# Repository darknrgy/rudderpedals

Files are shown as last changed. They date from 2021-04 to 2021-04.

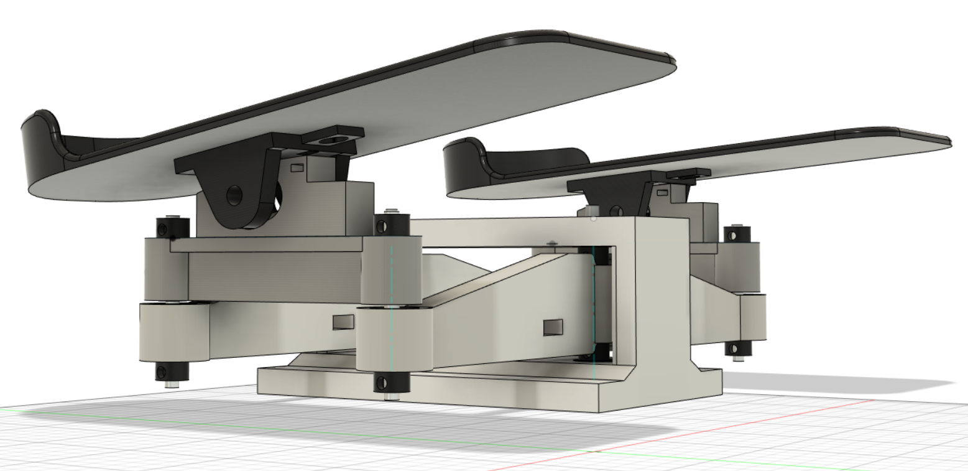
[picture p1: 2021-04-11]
Images/Pedal Assembly.png

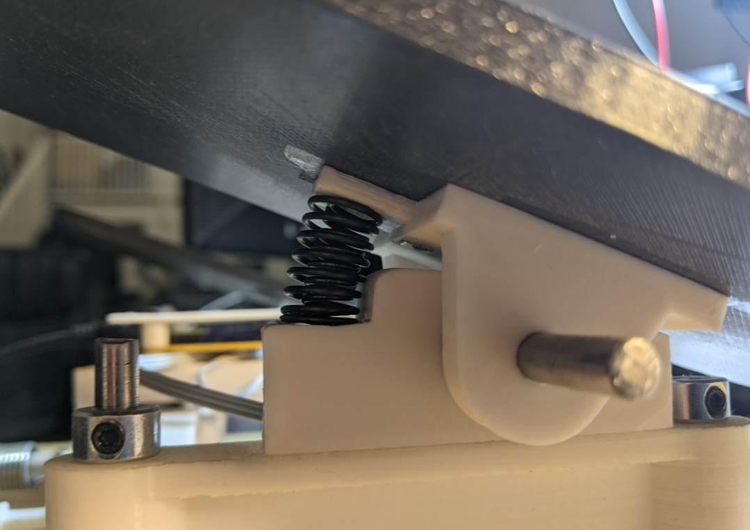
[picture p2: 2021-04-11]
Images/Pedal Spring.png

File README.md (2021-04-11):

# 3D Printed Flight Simulator Rudder Pedals

This is a set of flight simulator rudder pedals that I built from scratch. My copy is currently functional and being used in Microsoft Flight Simulator. This is a fairly crude design and is provided as-is with no support. Expect to iterate and improve the design. 

https://www.thingiverse.com/thing:4824134

https://youtu.be/vinw3yeDGUQ

## Materials
- All parts printed in PLA on an Anycubic Chiron
- Shims - https://www.amazon.com/gp/product/B004K1FF0K/ref=ppx_yo_dt_b_search_asin_title?ie=UTF8&psc=1
- Bearings - https://www.amazon.com/gp/product/B07GT739PV/ref=ppx_yo_dt_b_search_asin_title?ie=UTF8&psc=1
- Shaft - https://www.mcmaster.com/catalog/127/1241
- Collar - https://www.mcmaster.com/catalog/127/1335
- Hall sensor - https://www.digikey.com/en/products/detail/honeywell-sensing-and-productivity-solutions/SS49E/701361
- Main Spring - https://www.thespringstore.com/pe076-718-24014-mw-2750-mh-n-in.html
- Pedal Spring Options - https://www.amazon.com/gp/product/B008RG8LXW/ref=ppx_yo_dt_b_search_asin_title?ie=UTF8&psc=1
- Magnets - Search amazon for "5mm cube magnets" for the lowest price
- Arduino Micro
- Various wires, header pins, usb cable, nuts and bolts

## Construction Notes
- Reference the youtube video for additional notes
- Reference the included images
- The arms are 300mm long and will dictate the minimum size printer (but they can be printed diaganoally)
- The shafts must be cut to size and their diameter must be ground down to fit in the bearings. I put the cut shafts into a drill press and ground them with sand paper. 
- There are 8 shafts total:
  - 61mm rail shaft X4
  - 57mm pedal shaft X2
  - 72mm center shaft X2
- Some pieces are glued together with super thin cyanoacrolate (superglue). For best adhesion, sand the mating surfaces down to a very fine grain - 1000 git or more, and apply a thin and even layer of glue. 
  - Pedal is glued to Pedal Hinge
  - Rail Top is glued to Rail Bottom
  - Hall Sensor Mount is glued to Frame
  - Magnet Mount is glued to one of the Arms
- The hall sensor I chose may not be the best candidate. I get less resolution than I would really want. One of the parameters in the datasheet is "Magnetic Range", which for the SS49E is +/- 1000 Gauss. If I were to do it again, I would choose a smaller magnetic range for higher resolution. 
- The magnets interact with the sensor in a way that requires a specific orientation and distances. Experiment with a simple test setup to familiarize yourself with the behavior. 
- The circuit is very simple. It is powered by the usb port. The hall sensors require 5V, ground, and output a 0-5v signal that is read with analogRead(). 
- Pay special attention to how the springs are mounted in the video - they are latching and will self center. 
- The assembled product was mounted to a board with screws. The Spring Posts are hot glued to the board. 

## Programming Notes
- This project uses Arduino Joystick Library https://github.com/MHeironimus/ArduinoJoystickLibrary
- ArduinoJoystickLibrary requires an arduino or clone that uses the ATmega32u4, although I expect that the library could be ported if you have more programming skill than ATmega32u4 buying skills. 
- There is a physical calibration step that is independent of Windows joystick calibration. I printed values from within the microcontroller over serial and tuned these values for each axis:
  -	top - the highest raw ADC value
  - bottom - the lowest raw ADC value
  - expoV - exponential curve coefficient, 1 is linear, see source for my values. You may find a more formal way of finding this value but I just used trial and error.

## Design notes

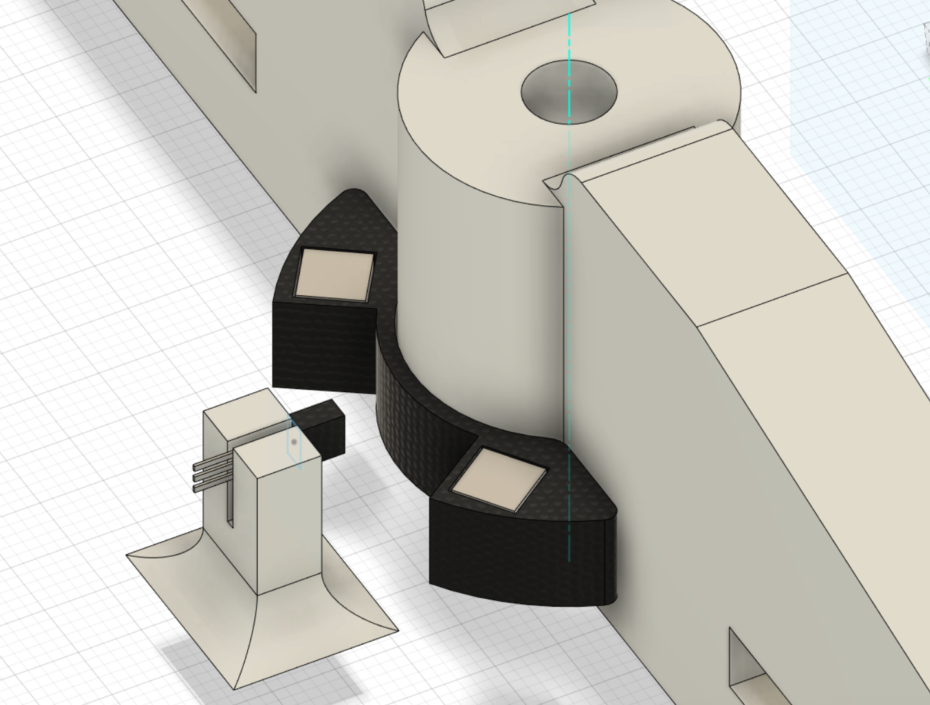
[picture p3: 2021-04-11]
Images/Hall Sensor.png

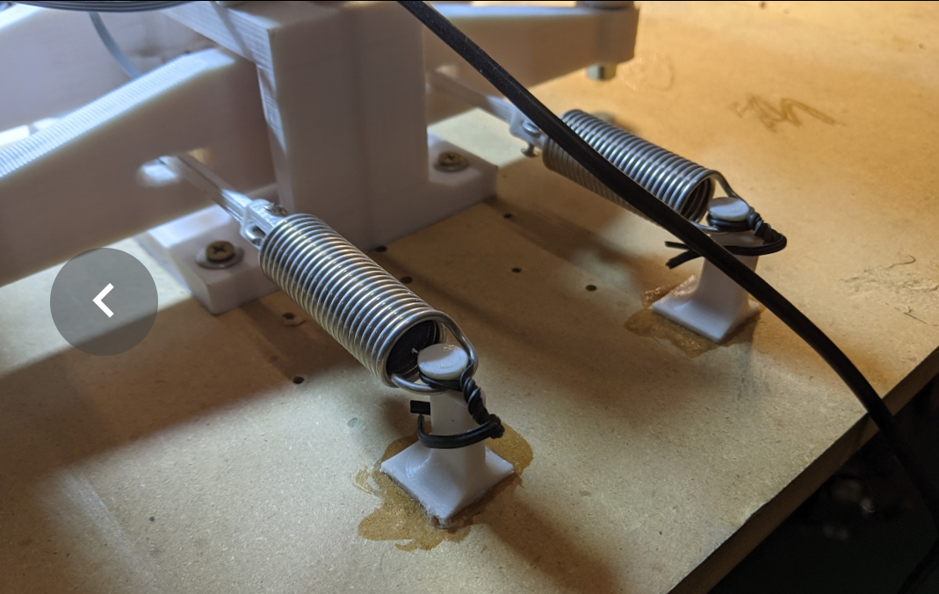
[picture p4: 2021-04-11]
Images/Main Spring.png

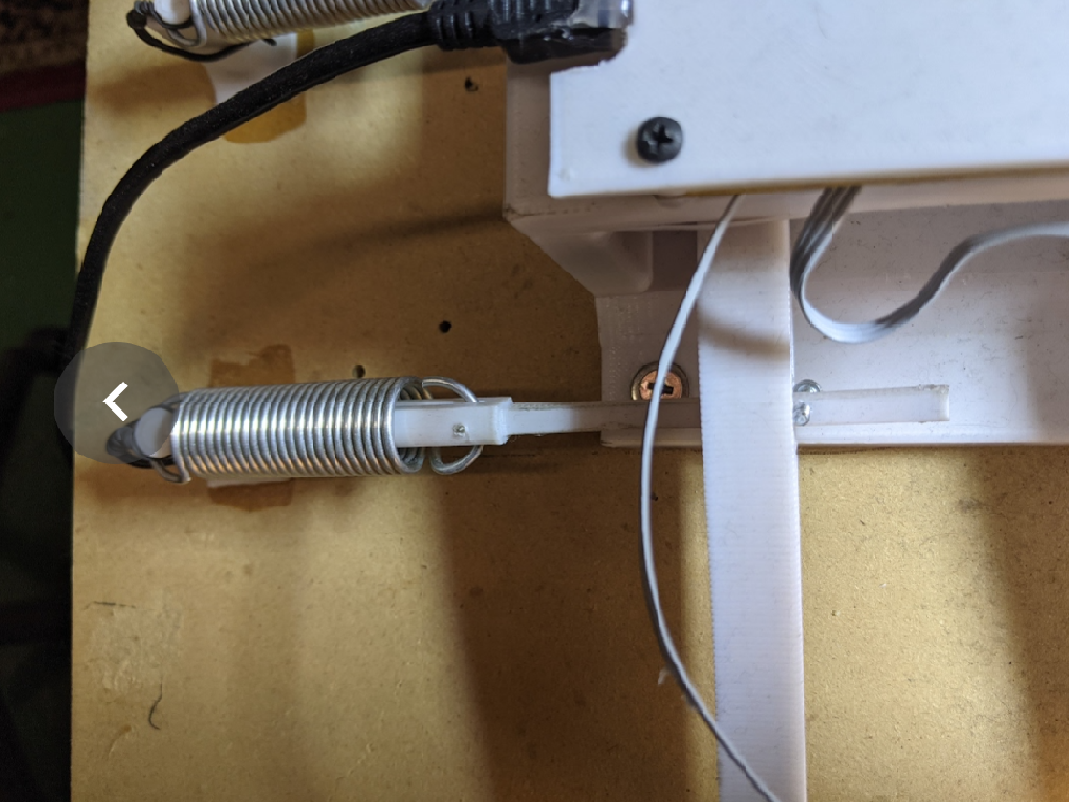
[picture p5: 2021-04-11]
Images/Main Spring (overhead).png

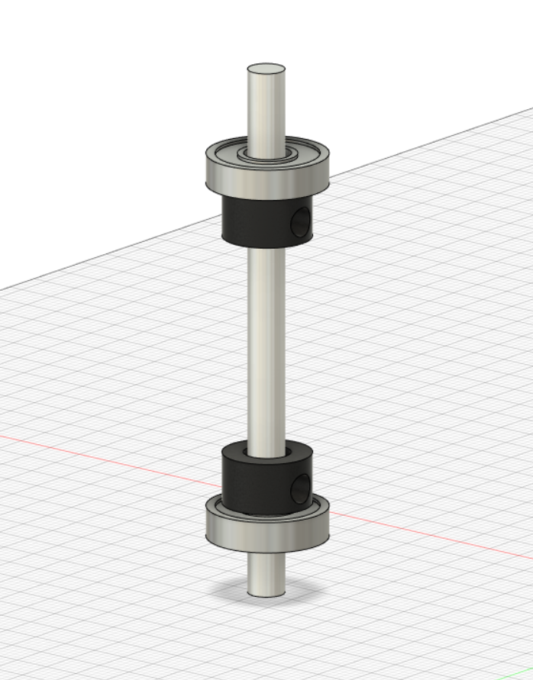
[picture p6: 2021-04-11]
Images/Center Shaft.png

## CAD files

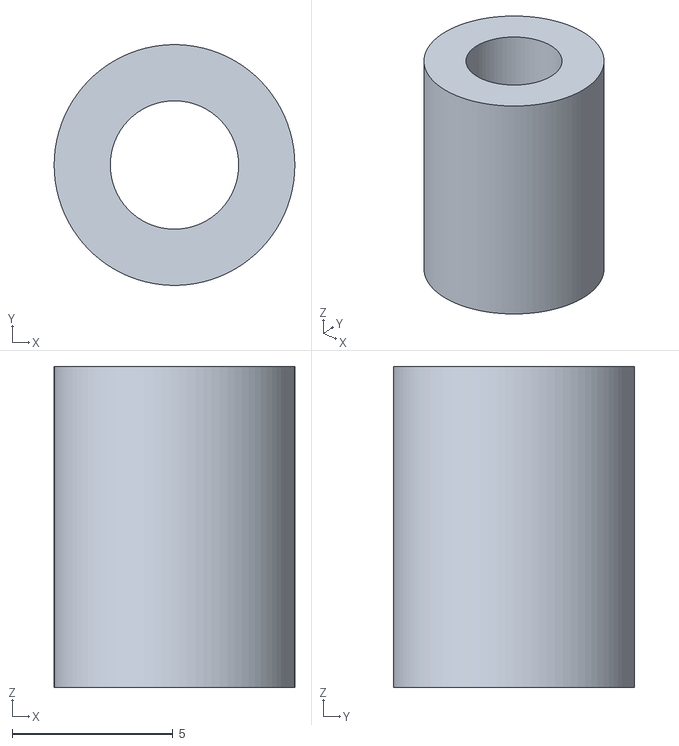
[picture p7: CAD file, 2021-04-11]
STL/Circuit Board Riser.stl
7.50 x 7.50 x 10.0

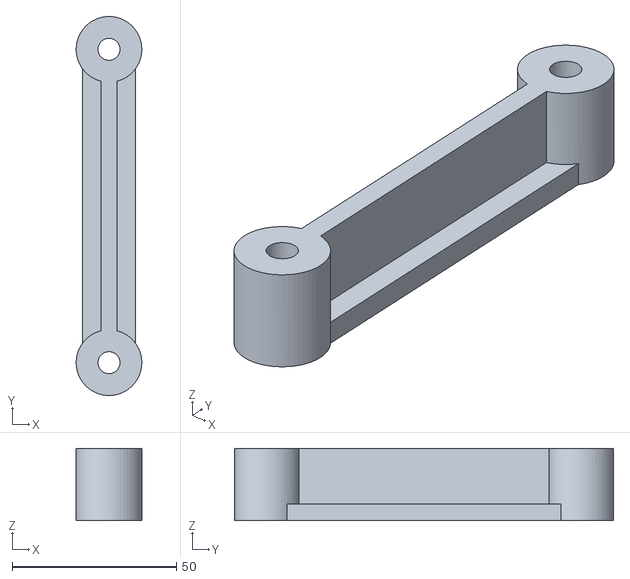
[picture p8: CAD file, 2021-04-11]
STL/Rail Bottom.stl
20.0 x 115.4 x 22.0

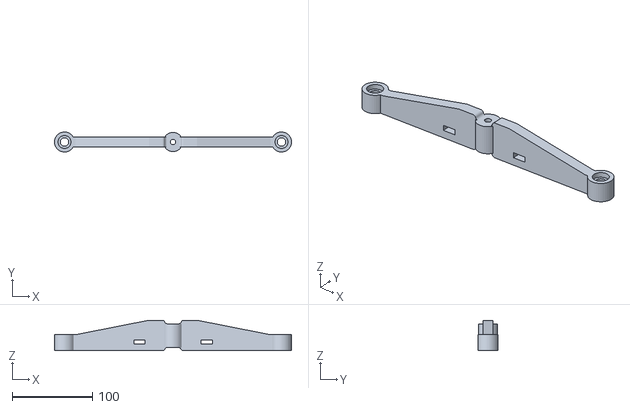
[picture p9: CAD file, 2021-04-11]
STL/Arm.stl
295.5 x 25.0 x 38.0

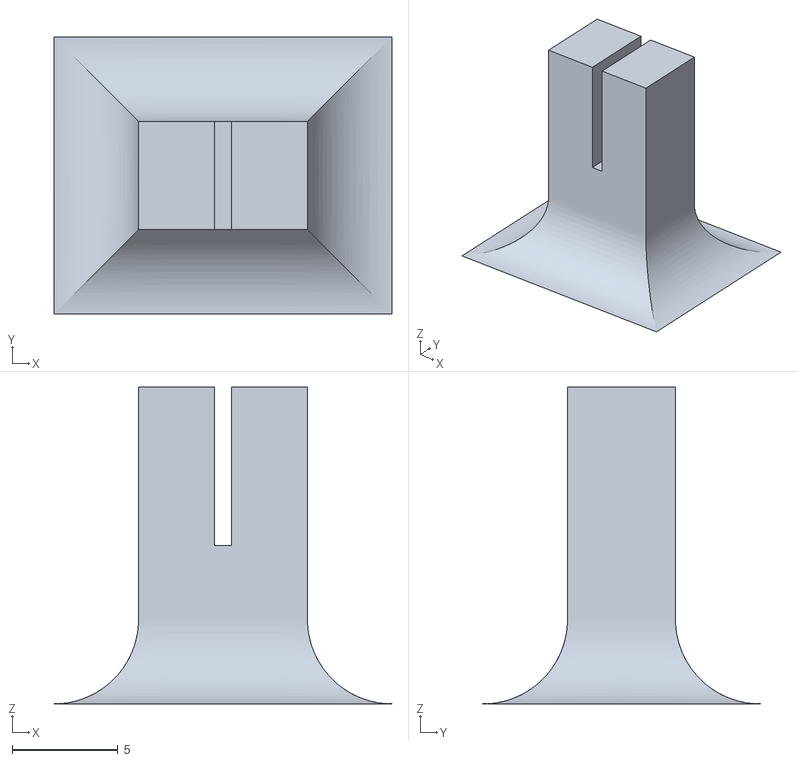
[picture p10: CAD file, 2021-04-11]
STL/Hall Sensor Mount.stl
16.0 x 13.1 x 15.0

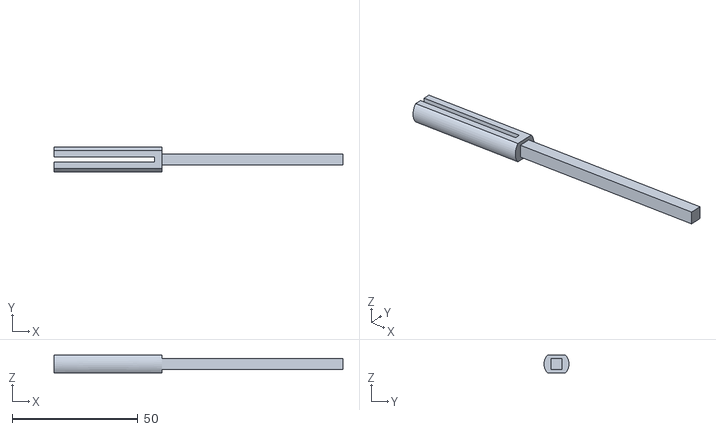
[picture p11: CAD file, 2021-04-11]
STL/Spring Rod.stl
115.0 x 10.0 x 7.00

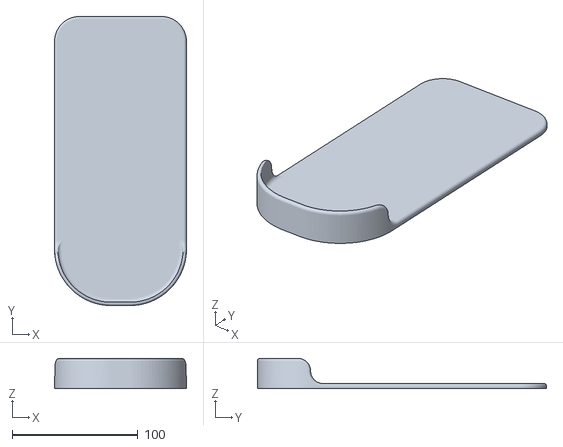
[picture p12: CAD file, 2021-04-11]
STL/Pedal.stl
105.0 x 230.0 x 24.0

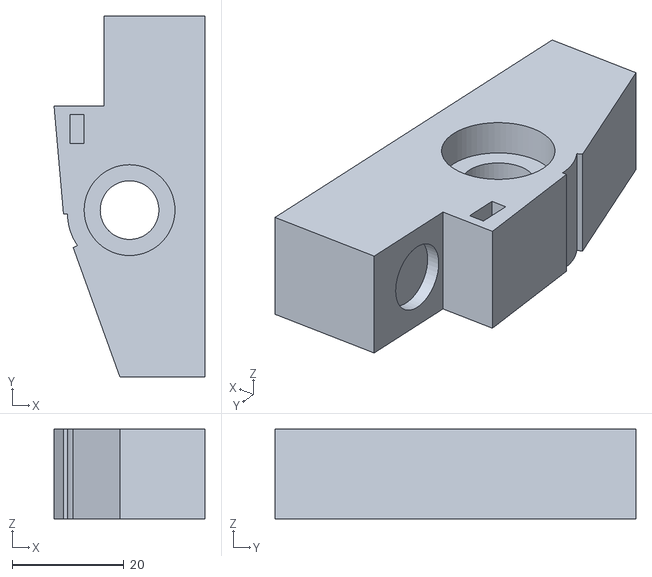
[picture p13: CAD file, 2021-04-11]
STL/Rail Top.stl
27.0 x 64.4 x 16.0

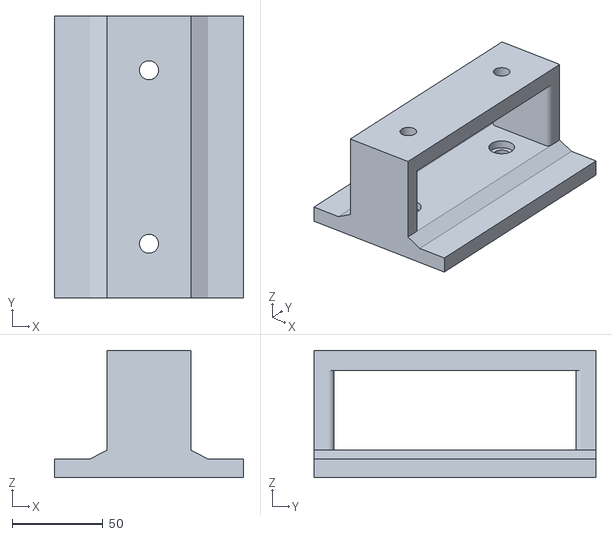
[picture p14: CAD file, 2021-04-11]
STL/Frame.stl
104.0 x 155.0 x 70.0

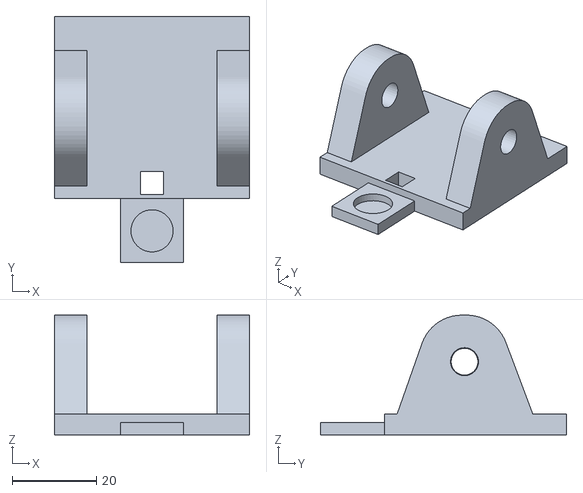
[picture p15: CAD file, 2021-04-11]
STL/Pedal Hinge.stl
46.3 x 58.3 x 28.4

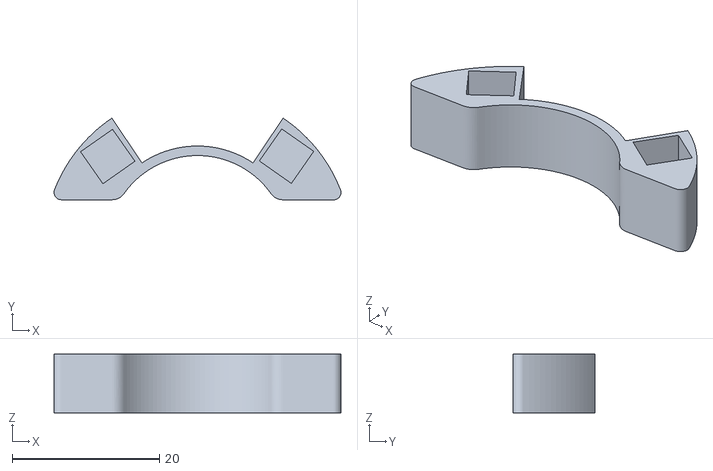
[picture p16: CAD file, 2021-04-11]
STL/Magnet Mount.stl
38.9 x 11.1 x 8.00

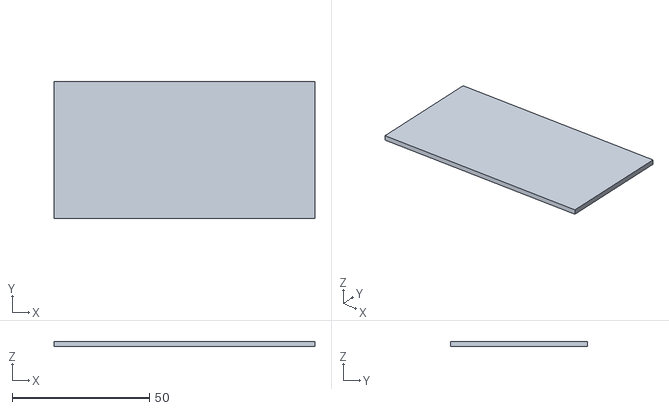
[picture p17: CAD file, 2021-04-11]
STL/Circuit Board Panel.stl
95.0 x 50.0 x 2.00

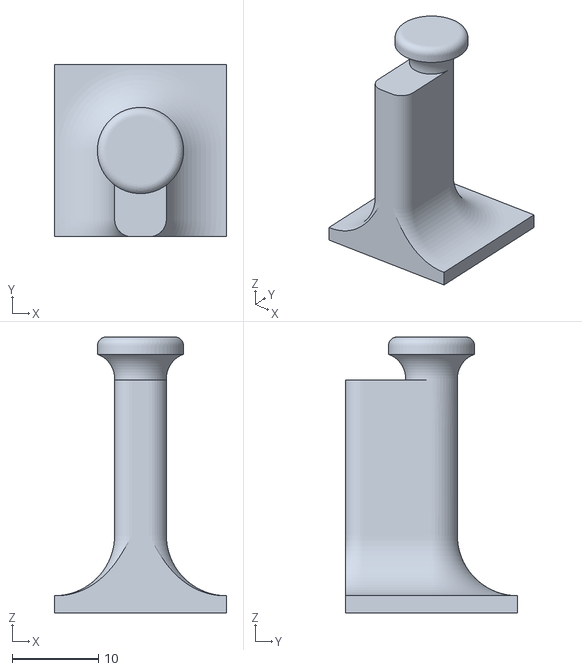
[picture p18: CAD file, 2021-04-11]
STL/Spring Post.stl
20.0 x 20.0 x 32.0

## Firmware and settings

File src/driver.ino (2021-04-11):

#include "Joystick.h" // ArduinoJoystickLibrary
Joystick_ Joystick;

void setup() {
  Serial.begin(9600);
 
  Joystick.setXAxisRange(0, 512);
  Joystick.setYAxisRange(0, 512);
  Joystick.setZAxisRange(-512, 512);
  Joystick.begin(false);
}

void loop() {
	rightBrake();
	leftBrake();
	yaw();
	Joystick.sendState();
	delay(10);

}

float rightBrake() {
	float top = 483;
	float bottom = 323;
	float expoV = 2;

	int sensorValue = analogRead(A1);

	/*Serial.print(sensorValue);
	Serial.print("\t");*/

	float value = normalizeOne(sensorValue, top, bottom);

	value = expo(value, expoV);
	value *= 512;
	value = limit(value, 512, 0);

	Joystick.setXAxis((int) value);
}

float leftBrake() {
	float top = 492;
	float bottom = 300;
	float expoV = 3;

	int sensorValue = analogRead(A2);

	/*Serial.print(sensorValue);
	Serial.print("\t");*/

	float value = normalizeOne(sensorValue, top, bottom);

	value = expo(value, expoV);
	value *= 512;

	value = limit(value, 512, 0);

	Joystick.setYAxis((int) value);
}

int yaw() {
	float top = 860;
	float bottom = 300;
	float center = 525;
	float expoV = 0.625;

	int sensorValue = analogRead(A3);

/*	Serial.print(sensorValue);
	Serial.print("\n");*/

	float value = normalize(sensorValue, top, bottom, center);

	value = expo(value, expoV);
	value *= 512; 

	value = limit(value, 512, -512);

	Joystick.setZAxis((int) value);
}

float normalize(float value, float top, float bottom, float center) {
	
	if (value == center) {
		return 0;
	}

	if (value > center) {
		return normalizeOne(value, top, center);
	} else {
		return - (1 - normalizeOne(value, center, bottom));
	}
}

float normalizeOne(float value, float top, float bottom) {
	if (value > top) value = top;
	if (value < bottom) value = bottom;
	value = value - bottom;
	return value / (top - bottom);
}

float expo(float input, float expo) {
	float value = pow(abs(input), expo);
	if (input < 0) value *= -1;
	return value;

}

int limit(int value, int top, int bottom) {
	if (value > top) return top;
	if (value < bottom) return bottom;
	return value;
}
